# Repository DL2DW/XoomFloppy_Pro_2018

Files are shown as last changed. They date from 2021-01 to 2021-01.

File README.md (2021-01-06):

# XoomFloppy Pro

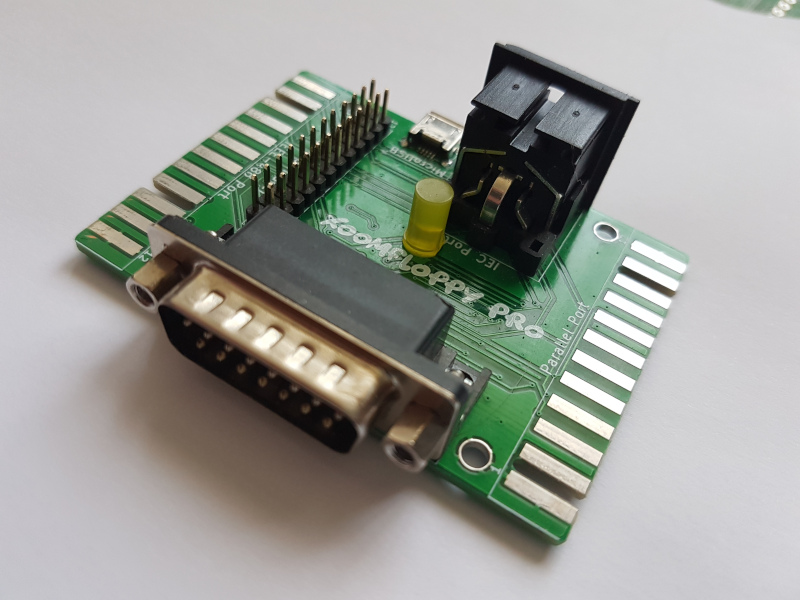
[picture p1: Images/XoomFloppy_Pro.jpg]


## Introduction

After I had built the small [XoomFloppy](https://github.com/DL2DW/XoomFloppy_2018) in USB format, some people asked me if it is not possible to "make" one or the other connector on it.

I then developed the XoomFloppy Pro.  This is the full version of the ZoomFloppy. So also with IEEE-488 and parallel cable connection.

But for this version I decided to use the same IEEE-488 connector as for the PET and CBM devices. So as a platinum connector. Because with the Commodore drives there were always appropriate cables included, which use exactly this connection.

So one saves corresponding adapter solutions.

Otherwise, this is practically a replica of the ZoomFloppy, only much smaller, more compact and with the possibility to print out a corresponding housing.

# Technical

I basically just shrunk the ZoomFloppy. Otherwise, everything that applies to the ZoomFloppy also applies to the XoomFloppy Pro.

But the hardware base is otherwise the same. This is now the second device that is 100% compatible with the ZoomFloppy.

The core is the ATmega32u2, on which the original firmware of the ZoomFloppy is flashed. But also the driver module 7406 is present.

In the Docs folder I put a manual in German, which explains the assembly and the subsequent installation of the firmware.

# Case

I have designed a small case, which everyone is welcome to print out for themselves. With it, the XoomFloppy is also very well protected and simply looks better.

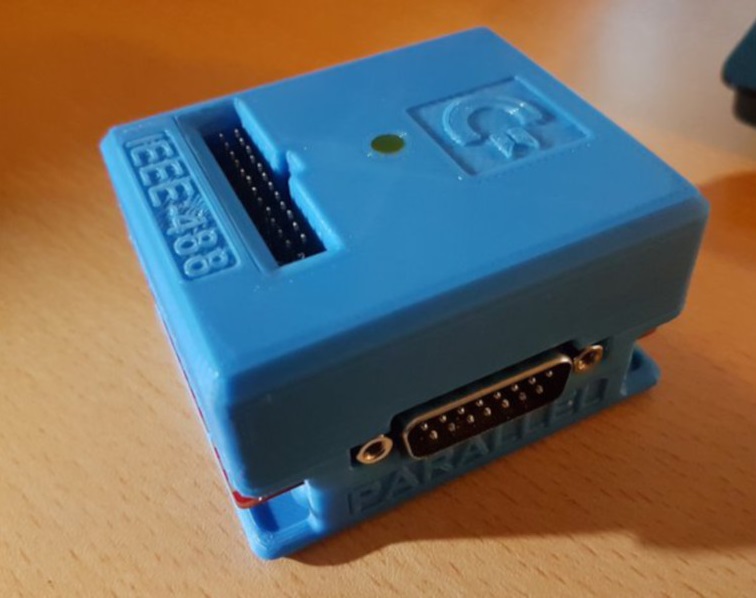
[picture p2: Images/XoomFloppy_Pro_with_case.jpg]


# BOM

The parts list consists of commercially available parts, which should actually be easy to obtain. If the housing is to be used, I recommend a 5mm round LED with the top flat. This will then fit flush into the housing.

| | Description | Part | References | Value | Footprint | Quantity Per PCB |
| ---- | --- | --- | --- | --- | --- | --- |
| 1 | Unpolarized capacitor | C | C1 C5 | 100n | C_0805_2012Metric | 2 |
| 2 | Unpolarized capacitor | C | C4 | 1µF | C_0805_2012Metric | 1 |
| 3 | Unpolarized capacitor | C | C2 C3 | 22pF | C_0805_2012Metric | 2 |
| 4 | Generic connector, double row, 02x12, top/bottom pin numbering scheme (row 1: 1...pins_per_row, row2: pins_per_row+1 ... num_pins), script generated (kicad-library-utils/schlib/autogen/connector/) | Conn_02x12_Top_Bottom | CN4 | IEEE-488 Port Stiftleiste | PinHeader_2x12_P2.54mm_Top_Bottom_Vertical_Mirror | 1 |
| 5 | | 618015231221 | CN3 | Parallel Port | 618015231221 | 1 |
| 6 | Light emitting diode | LED | D1 | LED Blue | LED_D3.0mm_Clear | 1 |
| 7 | TVS.3 3.5pF [SOT-23-6] | USBLC6-2SC6 | DZ1 | USBLC6-2SC6 | SOT-23-6 | 1 |
| 8 | Resettable fuse, polymeric positive temperature coefficient  | Polyfuse | F1 | Polyfuse 1206L150 | Fuse_1206_3216Metric | 1 |
| 9 | | 7406D | IC1 | 7406D | SOIC-14_3.9x8.7mm_P1.27mm | 1 |
| 10 | 6-pin DIN connector | DIN-6 | J1 | IEC | DIN-6 | 1 |
| 11 | USB Micro Type B connector | USB_B_Micro | J2 | USB_B_Micro | USB_Micro-B_Wuerth_629105150521 | 1 |
| 12 | Resistor | R | R2 R4 R6 R8 R10 R11 | 100k | R_0805_2012Metric | 6 |
| 13 | Resistor | R | R15 | 10k | R_0805_2012Metric | 1 |
| 14 | Resistor | R | R13 R14 | 22 | R_0805_2012Metric | 2 |
| 15 | Resistor | R | R12 | 220 | R_0805_2012Metric | 1 |
| 16 | Resistor | R | R1 R3 R5 R7 R9 | 4k7 | R_0805_2012Metric | 5 |
| 17 | 16MHz, 32kB Flash, 1kB SRAM, 1kB EEPROM, TQFP-32 | ATmega32U2-AU | U1 | ATmega32U2-AU | TQFP-32_7x7mm_P0.8mm | 1 |
| 18 | Two pin crystal | Crystal | Y1 | 16MHz | Crystal_SMD_5032-2Pin_5.0x3.2mm | 1 |

# PCB

The PCB can either be ordered directly from [PCBWay](https://www.pcbway.com/project/shareproject/XoomFloppy_Pro_1.html), or you can create it yourself from the Gerber files available here.

PCBWay (https://www.pcbway.com/project/shareproject/XoomFloppy_Pro_1.html)

If you liked my project, I would be very happy about a small coffee donation.



# License

The contents of this repository, with the exception of the Docs and Software directories, are released under the following license:

- the "Creative Commons Attribution-NonCommercial-ShareAlike 4.0 International License" (CC BY-NC-SA 4.0) full text of this license is included in the [LICENSE.CC-NC-BY-SA-4.0](https://github.com/DL2DW/XoomFloppy_Pro_2018/blob/main/LICENSE.CC-NC-BY-SA) file and a copy can also be found at https://creativecommons.org/licenses/by-nc-sa/4.0/

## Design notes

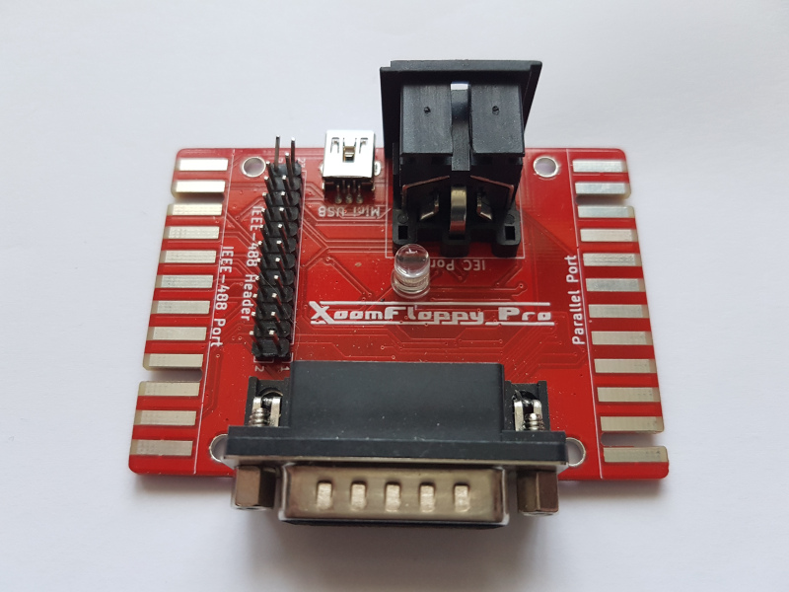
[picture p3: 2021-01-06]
Images/XoomFloppy_Pro_mit_Mini_USB.jpg

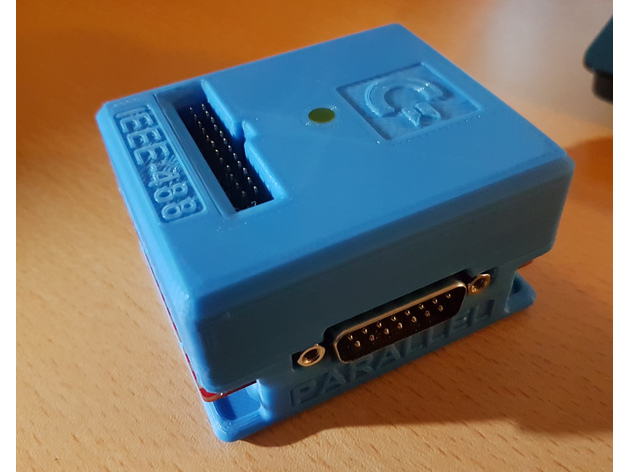
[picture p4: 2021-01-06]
Images/XoomFloppy_Pro_Case.jpg

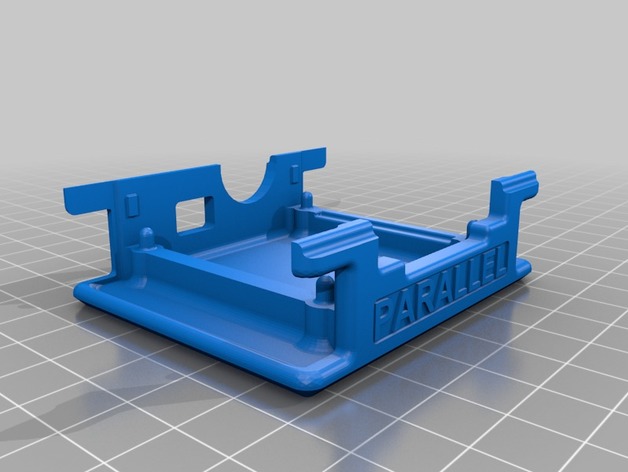
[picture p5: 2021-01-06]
Images/XoomFloppy_Pro_Case_bottom.jpg

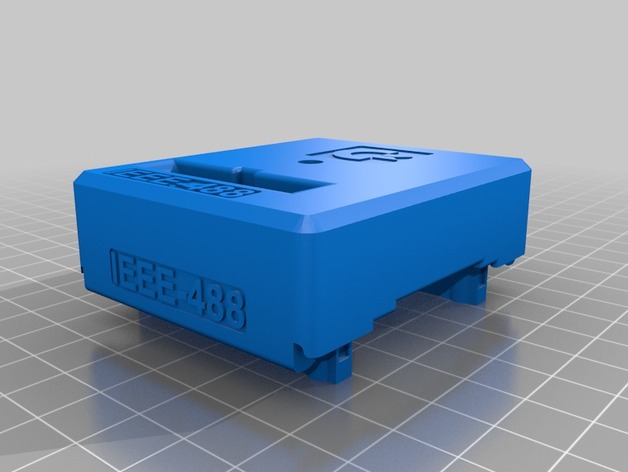
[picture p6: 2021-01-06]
Images/XoomFloppy_Pro_Case_top.jpg

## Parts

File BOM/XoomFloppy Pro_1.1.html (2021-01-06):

Source File | /Volumes/Daten/Elektronik/KiCad Neu/final/XoomFloppy Pro/XoomFloppy Pro.sch
BoM Date | Samstag, 25. Mai 2019 um 13:40:54
Schematic Version | 1.1
Schematic Date | 2019-05-25
KiCad Version | Eeschema (5.1.2-1)-1
Component Groups | 26
Component Count (per PCB) | 39
Fitted Components (per PCB) | 30
Number of PCBs | 1
Total Component Count (for 1 PCBs) | 30
 | Description | Part | References | Value | Footprint | Quantity Per PCB | Datasheet | Config | Feld8 | Feld6 | Feld4 | Feld5 | Feld7 | BOM
1 | Unpolarized capacitor | C | C1 C5 | 100n | C_0805_2012Metric | 2 | ~
2 | Unpolarized capacitor | C | C4 | 1µF | C_0805_2012Metric | 1 | ~
3 | Unpolarized capacitor | C | C2 C3 | 22pF | C_0805_2012Metric | 2 | ~
4 | Generic connector, double row, 02x12, top/bottom pin numbering scheme (row 1: 1...pins_per_row, row2: pins_per_row+1 ... num_pins), script generated (kicad-library-utils/schlib/autogen/connector/) | Conn_02x12_Top_Bottom | CN4 | IEEE-488 Port Stiftleiste | PinHeader_2x12_P2.54mm_Top_Bottom_Vertical_Mirror | 1 | ~
5 |  | 618015231221 | CN3 | Parallel Port | 618015231221 | 1 | 15 Way Right Angle Through Hole PCB D-sub Connector Plug, 2.77mm, 2.84mm Pitch |  | 618015231221 | Würth Elektronik | Bad | 3.25 USD | None
6 | Light emitting diode | LED | D1 | LED Blue | LED_D3.0mm_Clear | 1 | ~
7 | TVS.3 3.5pF [SOT-23-6] | USBLC6-2SC6 | DZ1 | USBLC6-2SC6 | SOT-23-6 | 1 | http://www.st.com/web/en/resource/technical/document/datasheet/CD00050750.pdf |  |  |  |  |  |  | TVS ST USBLC6-2SC6
8 | Resettable fuse, polymeric positive temperature coefficient | Polyfuse | F1 | Polyfuse 1206L150 | Fuse_1206_3216Metric | 1 | ~
9 |  | 7406D | IC1 | 7406D | SOIC-14_3.9x8.7mm_P1.27mm | 1
10 | 6-pin DIN connector | DIN-6 | J1 | IEC | DIN-6 | 1 | http://www.mouser.com/ds/2/18/40_c091_abd_e-75918.pdf
11 | USB Micro Type B connector | USB_B_Micro | J2 | USB_B_Micro | USB_Micro-B_Wuerth_629105150521 | 1 | ~
12 | Resistor | R | R2 R4 R6 R8 R10 R11 | 100k | R_0805_2012Metric | 6 | ~
13 | Resistor | R | R15 | 10k | R_0805_2012Metric | 1 | ~
14 | Resistor | R | R13 R14 | 22 | R_0805_2012Metric | 2 | ~
15 | Resistor | R | R12 | 220 | R_0805_2012Metric | 1 | ~
16 | Resistor | R | R1 R3 R5 R7 R9 | 4k7 | R_0805_2012Metric | 5 | ~
17 | 16MHz, 32kB Flash, 1kB SRAM, 1kB EEPROM, TQFP-32 | ATmega32U2-AU | U1 | ATmega32U2-AU | TQFP-32_7x7mm_P0.8mm | 1 | http://ww1.microchip.com/downloads/en/DeviceDoc/doc7799.pdf
18 | Two pin crystal | Crystal | Y1 | 16MHz | Crystal_SMD_5032-2Pin_5.0x3.2mm | 1 | ~

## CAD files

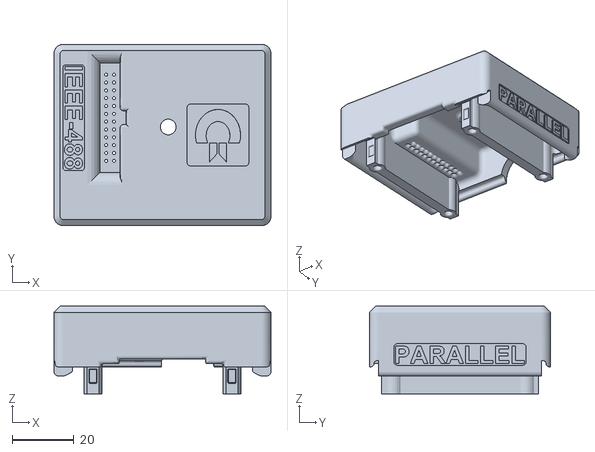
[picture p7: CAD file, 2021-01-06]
Case/Case_for_XoomFloppy_Pro_upper_side.stl
70.4 x 58.8 x 28.5

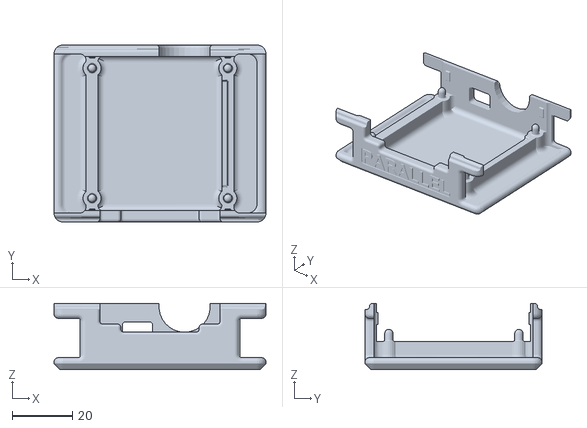
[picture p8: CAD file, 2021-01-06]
Case/Case_for_XoomFloppy_Pro_bottom.stl
70.4 x 58.8 x 22.0

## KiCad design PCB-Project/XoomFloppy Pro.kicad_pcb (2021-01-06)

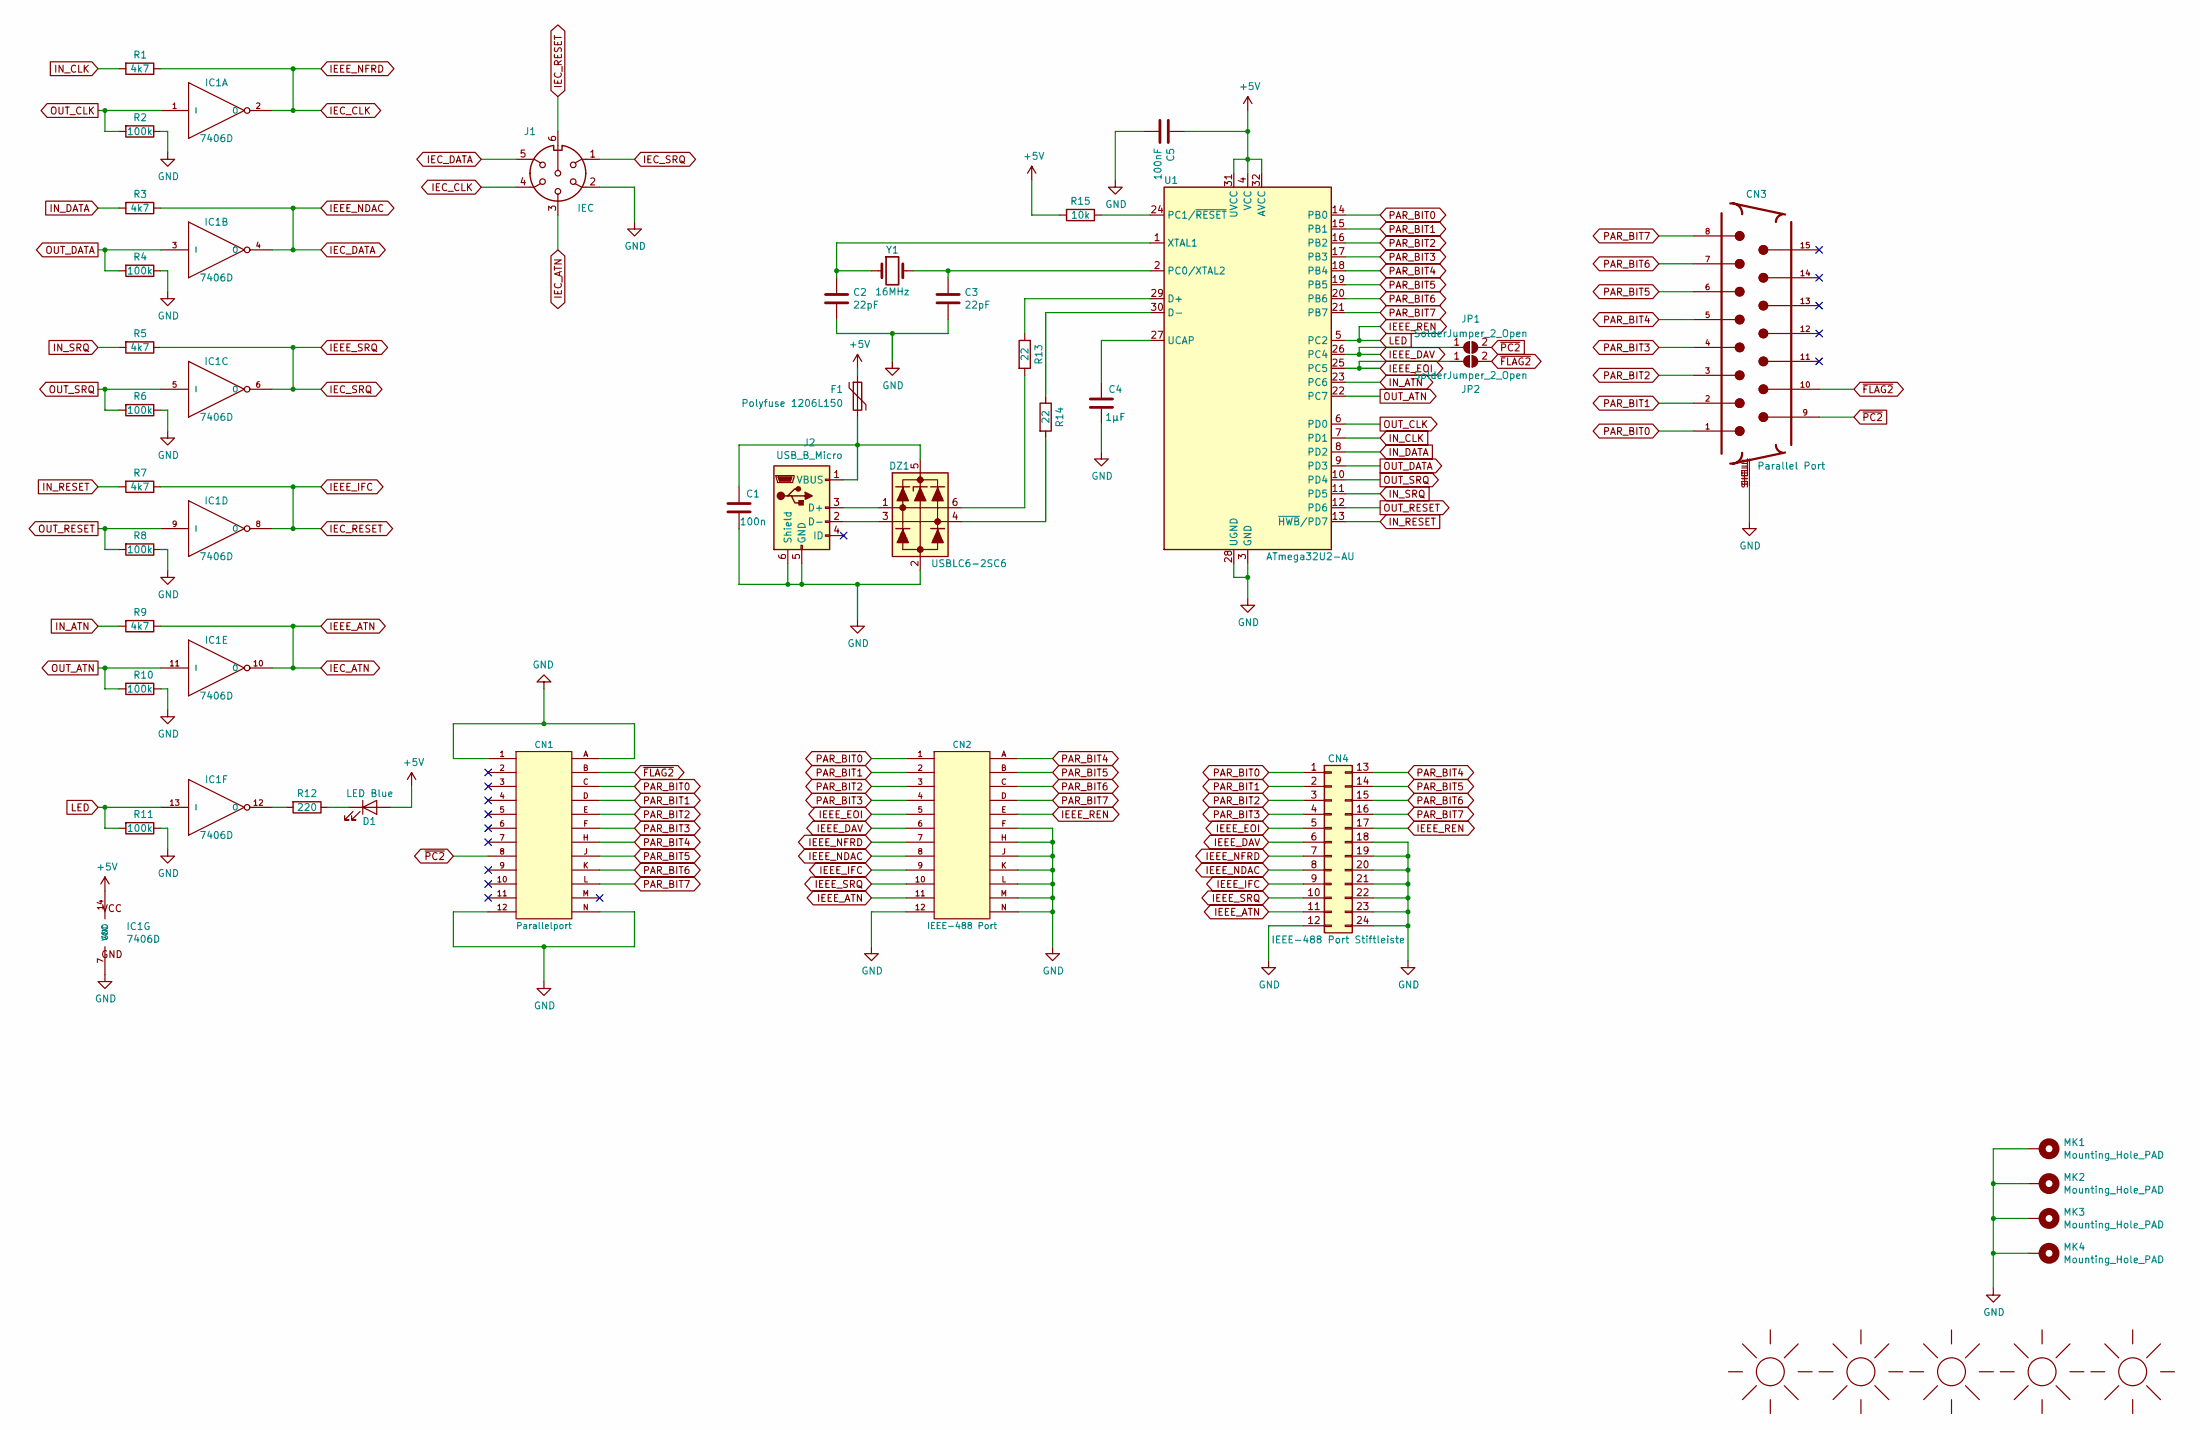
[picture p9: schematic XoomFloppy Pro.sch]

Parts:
C1: 100n; C_0805_2012Metric
C2, C3: 22pF; C_0805_2012Metric
C4: 1µF; C_0805_2012Metric
C5: 100nF; C_0805_2012Metric
CN1: Parallelport; Userport_Connector
CN2: IEEE-488 Port; Userport_Connector
CN3: Parallel Port; 618015231221
CN4: IEEE-488 Port Stiftleiste; PinHeader_2x12_P2.54mm_Top_Bottom_Vertical_Mirror
D1: LED Blue; LED_D3.0mm_Clear
DZ1: USBLC6-2SC6; SOT-23-6
F1: Polyfuse 1206L150; Fuse_1206_3216Metric
IC1: 7406D; SOIC-14_3.9x8.7mm_P1.27mm
J1: IEC; DIN-6
J2: USB_B_Micro; USB_Micro-B_Wuerth_629105150521
JP1, JP2: SolderJumper_2_Open; SolderJumper-2_P1.3mm_Open_RoundedPad1.0x1.5mm
M1: SUNLOGO; KiCad-Logo2_6mm_SilkScreen
M2: SUNLOGO; Logo_silk_CC-BY-NC-SA_10x3.6mm
M3: SUNLOGO; Logo_silk_OSHW_6x6mm
M4: SUNLOGO; DL2DW_Logo_Silk_20x10mm
M5: SUNLOGO; XoomFloppy Pro Schriftzug
MK1, MK2, MK3, MK4: Mounting_Hole_PAD; MountingHole_3.2mm_M3
R1, R3, R5, R7, R9: 4k7; R_0805_2012Metric
R2, R4, R6, R8, R10, R11: 100k; R_0805_2012Metric
R12: 220; R_0805_2012Metric
R13, R14: 22; R_0805_2012Metric
R15: 10k; R_0805_2012Metric
U1: ATmega32U2-AU; TQFP-32_7x7mm_P0.8mm
Y1: 16MHz; Crystal_SMD_5032-2Pin_5.0x3.2mm

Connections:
+5V: C5.2, D1.2 (A), F1.1, IC1.14 (VCC), R15.2, U1.4 (VCC), U1.31 (UVCC), U1.32 (AVCC)
GND: C1.1, C2.2, C3.2, C4.1, C5.1, CN1.1, CN1.12, CN1.A, CN1.N, CN2.12, CN2.F, CN2.H, CN2.J, CN2.K, CN2.L, CN2.M, CN2.N, CN3.SHELL (SHIELD), CN3.SHELL1 (SHIELD), CN4.12, CN4.18, CN4.19, CN4.20, CN4.21, CN4.22, CN4.23, CN4.24, DZ1.2, IC1.7 (GND), J1.2, J2.5 (GND), J2.6 (Shield), MK1.1, MK2.1, MK3.1, MK4.1, R2.1, R4.1, R6.1, R8.1, R10.1, R11.1, U1.3 (GND), U1.28 (UGND)
IEC_ATN: CN2.11, CN4.11, IC1.10 (O), J1.3, R9.1
IEC_CLK: CN2.7, CN4.7, IC1.2 (O), J1.4, R1.1
IEC_DATA: CN2.8, CN4.8, IC1.4 (O), J1.5, R3.1
IEC_RESET: CN2.9, CN4.9, IC1.8 (O), J1.6, R7.1
IEC_SRQ: CN2.10, CN4.10, IC1.6 (O), J1.1, R5.1
IEEE_DAV: CN2.6, CN4.6, JP1.1 (A), U1.26 (PC4)
IEEE_EOI: CN2.5, CN4.5, JP2.1 (A), U1.25 (PC5)
IEEE_REN: CN2.E, CN4.17, IC1.13 (I), R11.2, U1.5 (PC2)
IN_ATN: R9.2, U1.23 (PC6)
IN_CLK: R1.2, U1.7 (PD1)
IN_DATA: R3.2, U1.8 (PD2)
IN_RESET: R7.2, U1.13 (~HWB~/PD7)
IN_SRQ: R5.2, U1.11 (PD5)
unnamed: C1.2, DZ1.5, F1.2, J2.1 (VBUS)
unnamed: C2.1, U1.1 (XTAL1), Y1.1
unnamed: C3.1, U1.2 (PC0/XTAL2), Y1.2
unnamed: C4.2, U1.27 (UCAP)
unnamed: D1.1 (K), R12.1
unnamed: DZ1.1, J2.3 (D+)
unnamed: DZ1.3, J2.2 (D-)
unnamed: DZ1.4, R14.2
unnamed: DZ1.6, R13.2
unnamed: IC1.12 (O), R12.2
unnamed: R13.1, U1.29 (D+)
unnamed: R14.1, U1.30 (D-)
unnamed: R15.1, U1.24 (PC1/~RESET)
OUT_ATN: IC1.11 (I), R10.2, U1.22 (PC7)
OUT_CLK: IC1.1 (I), R2.2, U1.6 (PD0)
OUT_DATA: IC1.3 (I), R4.2, U1.9 (PD3)
OUT_RESET: IC1.9 (I), R8.2, U1.12 (PD6)
OUT_SRQ: IC1.5 (I), R6.2, U1.10 (PD4)
PAR_BIT0: CN1.C, CN2.1, CN3.1, CN4.1, U1.14 (PB0)
PAR_BIT1: CN1.D, CN2.2, CN3.2, CN4.2, U1.15 (PB1)
PAR_BIT2: CN1.E, CN2.3, CN3.3, CN4.3, U1.16 (PB2)
PAR_BIT3: CN1.F, CN2.4, CN3.4, CN4.4, U1.17 (PB3)
PAR_BIT4: CN1.H, CN2.A, CN3.5, CN4.13, U1.18 (PB4)
PAR_BIT5: CN1.J, CN2.B, CN3.6, CN4.14, U1.19 (PB5)
PAR_BIT6: CN1.K, CN2.C, CN3.7, CN4.15, U1.20 (PB6)
PAR_BIT7: CN1.L, CN2.D, CN3.8, CN4.16, U1.21 (PB7)
~FLAG2: CN1.B, CN3.10, JP2.2 (B)
~PC2: CN1.8, CN3.9, JP1.2 (B)

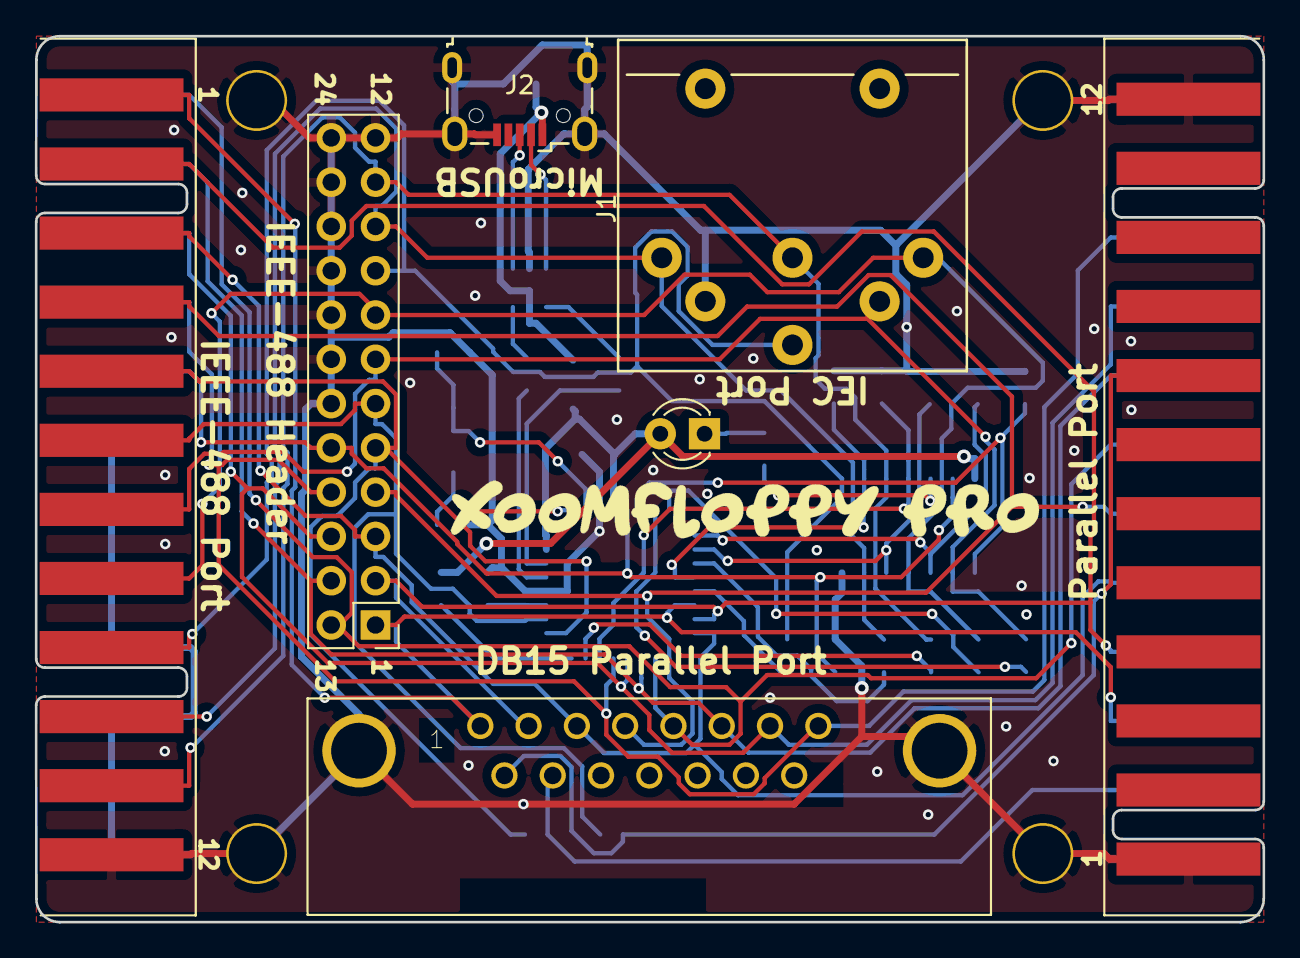
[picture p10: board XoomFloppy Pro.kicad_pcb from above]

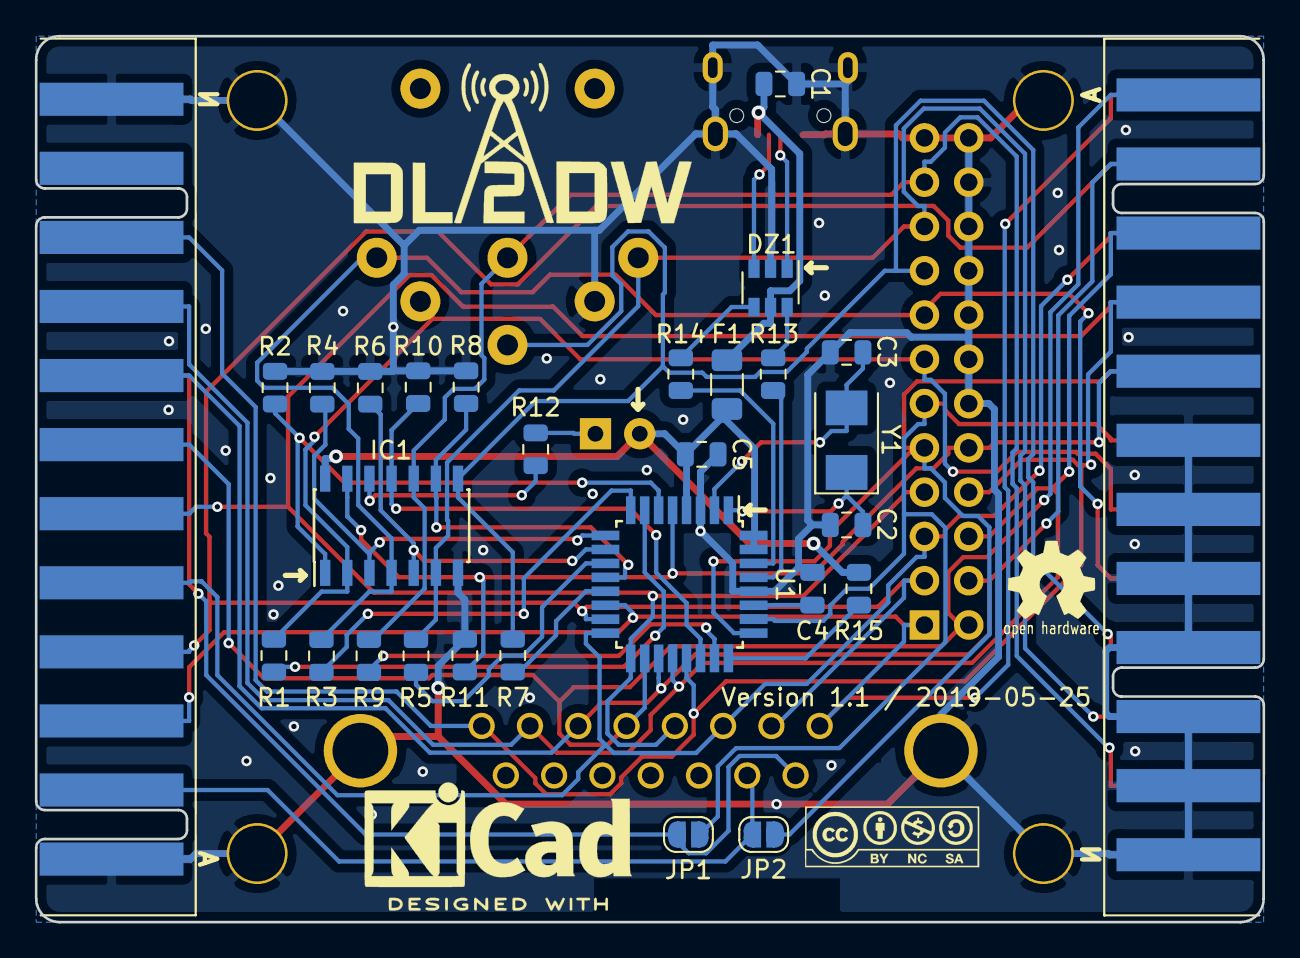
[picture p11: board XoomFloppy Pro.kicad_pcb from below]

Board: 2 copper layers, 70.4 x 50.8 mm, 43 parts (31 on the bottom side), 43 nets.
